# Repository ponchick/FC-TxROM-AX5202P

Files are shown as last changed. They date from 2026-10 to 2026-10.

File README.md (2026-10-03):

# FC-TxROM-AX5202P

Cartridge PCB with an MMC3 mapper built around the AX5202P IC.

In theory, such a cartridge should support all TxROM-family board types. In practice, only the most common variants have been tested — no issues were found.

Russian version: [`README.ru.md`](README.ru.md)

## PRG RAM and battery support

The board supports PRG RAM for save data. A CR2032 cell retains data when the console is powered off.

- **If a battery is installed** (saves are required) — leave the **NO BATTERY** jumpers **open** (do not bridge them).
- **If no battery is used** (PRG RAM is on the board but saves are not needed) — bridge **both** **NO BATTERY** jumpers. PRG RAM is then powered from the console’s main supply, and data is lost when power is removed.

In no-battery mode, the following parts may be omitted:

- Battery BT1
- Resistors R1, R2, R3, R4
- Capacitors C4, C8
- Diodes D1, D2
- Transistor Q1

## CHR ROM / CHR RAM selection

Some games need RAM instead of ROM for pattern tables. Selection is done with three jumpers on the board:

- **CHR ROM mode** — bridge the upper pair of pads.
- **CHR RAM mode** — bridge the lower pair of pads.

## Mirror Control (mapper 118 support)

The two **MIRROR CONTROL** jumpers route `CHR A17` and `CIRAM A10`. This is required for correct operation of different TxROM board subtypes.

- **Upper position** — for mapper 118 (**TKSROM** and **TLSROM** boards).
- **Lower position** — for standard TxROM (e.g. **TKROM**, **TLROM**) and most other MMC3 games.

If you do not use mapper 118, keep the jumpers in the lower position.

## ROM type selection (pinout)

Two jumpers switch pins 1 and 31 of the ROM IC, because those pins differ between memory types.

- **Upper position** (`EEPROM/FLASH`) — for electrically erasable ROM (EEPROM) and FLASH.
- **Lower position** (`UV EPROM`) — for UV-erasable EPROM.

Set the jumpers to match the ROM you install.

## License

This project is licensed under **CERN Open Hardware Licence Version 2 – Permissive** (`CERN-OHL-P-2.0`).  
See `LICENSE` for details.

SPDX-License-Identifier: `CERN-OHL-P-2.0`

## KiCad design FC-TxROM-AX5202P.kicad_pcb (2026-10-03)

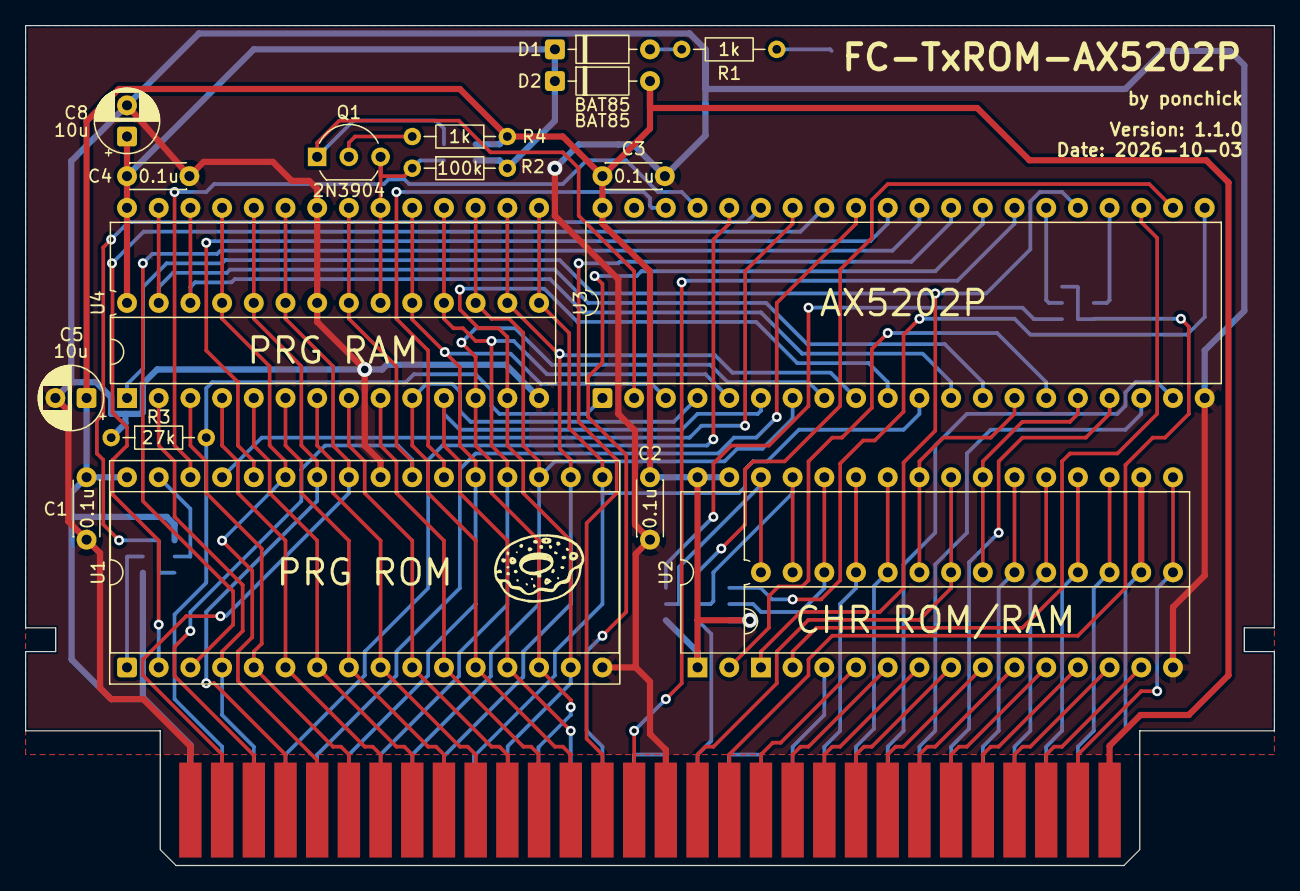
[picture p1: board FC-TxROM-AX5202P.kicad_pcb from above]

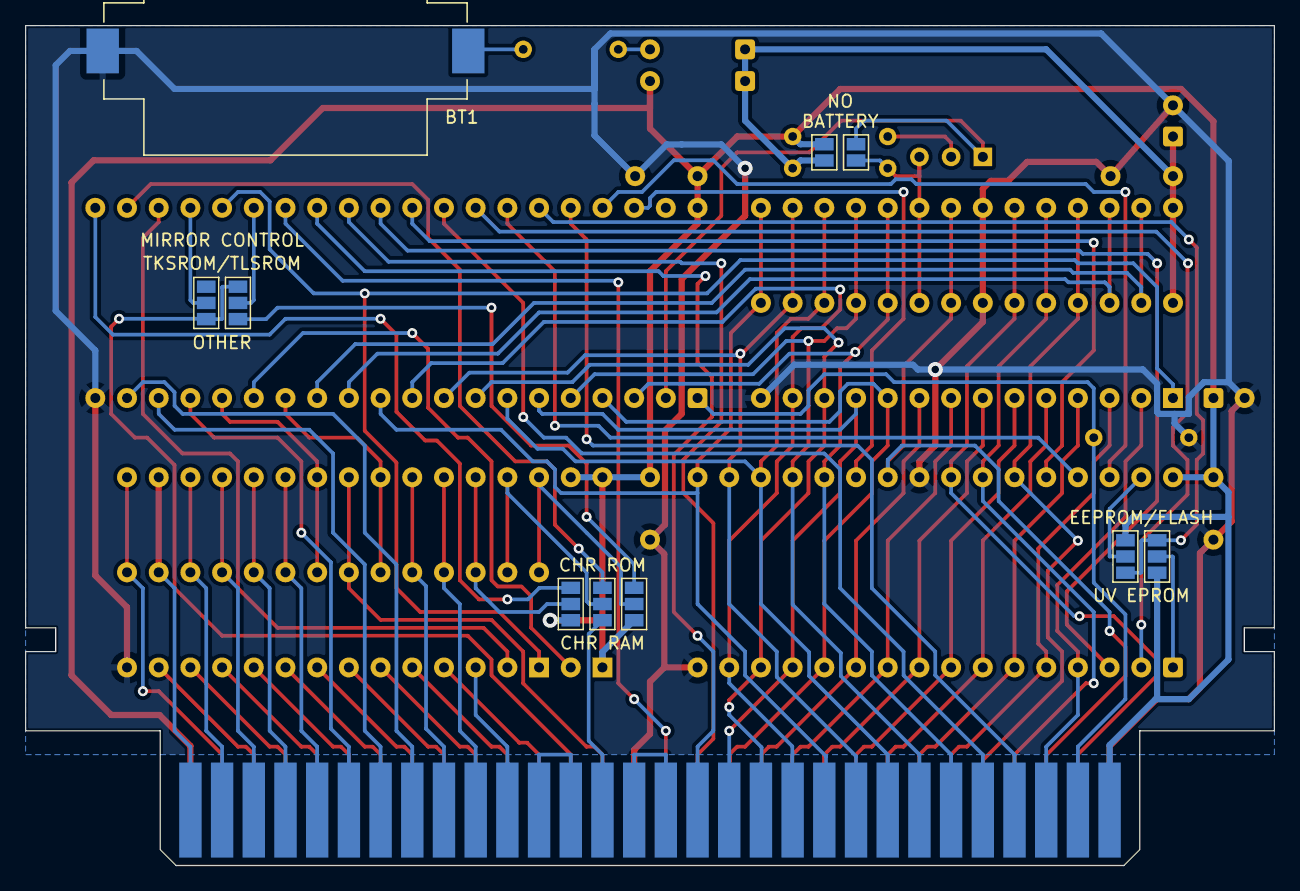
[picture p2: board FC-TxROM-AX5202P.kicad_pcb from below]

Board: 2 copper layers, 100.1 x 67.3 mm, 29 parts (10 on the bottom side), 86 nets.

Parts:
BT1: 2032; BatteryHolder_Keystone_1060_1x2032
C1, C2, C3, C4: 0.1u; C_Disc_D4.3mm_W1.9mm_P5.00mm
C5, C8: 10u; CP_Radial_D5.0mm_P2.50mm
D1, D2: BAT85; D_DO-35_SOD27_P7.62mm_Horizontal
J1: FAMICOM_EDGE; CONN_EDGE_2x60
JP1: +CE1 / A13; Jumper-3
JP2: ~{WE} / A14; Jumper-3
JP3, JP4: TKSROM/TLSROM/OTHER; Jumper-3
JP5: VDD / A17; Jumper-3
JP6, JP7: EPROM/FLASH; Jumper-3
JP8: UNSAFE_CE; SolderJumper-2_P1.3mm_Open_Pad1.0x1.5mm
JP9: SRAM_VCC; SolderJumper-2_P1.3mm_Open_Pad1.0x1.5mm
LOGO#: LOGO; ponchick
Q1: 2N3904; TO-92_Inline_Wide
R1, R4: 1k; R_Axial_DIN0204_L3.6mm_D1.6mm_P7.62mm_Horizontal
R2: 100k; R_Axial_DIN0204_L3.6mm_D1.6mm_P7.62mm_Horizontal
R3: 27k; R_Axial_DIN0204_L3.6mm_D1.6mm_P7.62mm_Horizontal
U1: PRG ROM; DIP-32_W15.24mm_Socket
U2: CHR ROM/RAM; DIP-32_Triple
U3: AX5202P; DIP-40_W15.24mm
U4: PRG RAM; DIP-28_Dual

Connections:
/CHR_A10: U2.23 (A10), U3.16 (CHR_A10)
/CHR_A11: U2.25 (A11), U3.14 (CHR_A11)
/CHR_A12: U2.4 (A12), U3.23 (CHR_A12)
/CHR_A13: JP1.1 (A), U3.21 (CHR_A13)
/CHR_A14: JP2.1 (A), U3.22 (CHR_A14)
/CHR_A15: U2.3 (A15), U3.25 (CHR_A15), U4.1 (NC)
/CHR_A16: U2.2 (A16), U3.15 (CHR_A16)
/CHR_A17: JP3.2 (C), U3.26 (CHR_A17)
/CHR_PIN26: JP1.2 (C), U2.28 (A13)
/CHR_PIN27: JP2.2 (C), U2.29 (A14)
/CHR_PIN28: JP5.2 (C), U2.30 (A17)
/CHR_PIN28_A17: JP3.3 (B), JP5.1 (A)
/CIRAM_A10: JP4.2 (C), U3.24 (CIRAM_A10)
/CPU_A0: J1.13 (CPU_A0), U1.12 (A0), U3.4 (CPU_A0), U4.10 (A0)
/CPU_A1: J1.12 (CPU_A1), U1.11 (A1), U4.9 (A1)
/CPU_A2: J1.11 (CPU_A2), U1.10 (A2), U4.8 (A2)
/CPU_A3: J1.10 (CPU_A3), U1.9 (A3), U4.7 (A3)
/CPU_A4: J1.9 (CPU_A4), U1.8 (A4), U4.6 (A4)
/CPU_A5: J1.8 (CPU_A5), U1.7 (A5), U4.5 (A5)
/CPU_A6: J1.7 (CPU_A6), U1.6 (A6), U4.4 (A6)
/CPU_A7: J1.6 (CPU_A7), U1.5 (A7), U4.3 (A7)
/CPU_A8: J1.5 (CPU_A8), U1.27 (A8), U4.25 (A8)
/CPU_A9: J1.4 (CPU_A9), U1.26 (A9), U4.24 (A9)
/CPU_A10: J1.3 (CPU_A10), U1.23 (A10), U4.21 (A10)
/CPU_A11: J1.2 (CPU_A11), U1.25 (A11), U4.23 (A11)
/CPU_A12: J1.33 (CPU_A12), U1.4 (A12), U4.2 (A12)
/CPU_A13: J1.34 (CPU_A13), U3.36 (CPU_A13)
/CPU_A14: J1.35 (CPU_A14), U3.32 (CPU_A14)
/CPU_D0: J1.43 (CPU_D0), U1.13 (D0), U3.6 (CPU_D0), U4.11 (Q0)
/CPU_D1: J1.42 (CPU_D1), U1.14 (D1), U3.8 (CPU_D1), U4.12 (Q1)
/CPU_D2: J1.41 (CPU_D2), U1.15 (D2), U3.10 (CPU_D2), U4.13 (Q2)
/CPU_D3: J1.40 (CPU_D3), U1.17 (D3), U3.11 (CPU_D3), U4.15 (Q3)
/CPU_D4: J1.39 (CPU_D4), U1.18 (D4), U3.9 (CPU_D4), U4.16 (Q4)
/CPU_D5: J1.38 (CPU_D5), U1.19 (D5), U3.7 (CPU_D5), U4.17 (Q5)
/CPU_D6: J1.37 (CPU_D6), U1.20 (D6), U3.5 (CPU_D6), U4.18 (Q6)
/CPU_D7: J1.36 (CPU_D7), U1.21 (D7), U3.3 (CPU_D7), U4.19 (Q7)
/CPU_RW: J1.14 (CPU_R/W), U3.29 (CPU_R/W)
/M2: J1.32 (M2), R3.2, U3.1 (M2)
/PPU_A0: J1.25 (PPU_A0), U2.12 (A0)
/PPU_A1: J1.24 (PPU_A1), U2.11 (A1)
/PPU_A2: J1.23 (PPU_A2), U2.10 (A2)
/PPU_A3: J1.22 (PPU_A3), U2.9 (A3)
/PPU_A4: J1.21 (PPU_A4), U2.8 (A4)
/PPU_A5: J1.20 (PPU_A5), U2.7 (A5)
/PPU_A6: J1.19 (PPU_A6), U2.6 (A6)
/PPU_A7: J1.50 (PPU_A7), U2.5 (A7)
/PPU_A8: J1.51 (PPU_A8), U2.27 (A8)
/PPU_A9: J1.52 (PPU_A9), U2.26 (A9)
/PPU_A10: J1.53 (PPU_A10), U3.19 (PPU_A10)
/PPU_A11: J1.54 (PPU_A11), U3.18 (PPU_A11)
/PPU_A12: J1.55 (PPU_A12), U3.17 (PPU_A12)
/PPU_A13: J1.56 (PPU_A13), U2.22 (CE)
/PPU_D0: J1.26 (PPU_D0), U2.13 (D0)
/PPU_D1: J1.27 (PPU_D1), U2.14 (D1)
/PPU_D2: J1.28 (PPU_D2), U2.15 (D2)
/PPU_D3: J1.29 (PPU_D3), U2.17 (D3)
/PPU_D4: J1.60 (PPU_D4), U2.18 (D4)
/PPU_D5: J1.59 (PPU_D5), U2.19 (D5)
/PPU_D6: J1.58 (PPU_D6), U2.20 (D6)
/PPU_D7: J1.57 (PPU_D7), U2.21 (D7)
/PRG_A13: U1.28 (A13), U3.31 (PRG_A13)
/PRG_A14: U1.29 (A14), U3.34 (PRG_A14)
/PRG_A15: U1.3 (A15), U3.30 (PRG_A15)
/PRG_A16: U1.2 (A16), U3.33 (PRG_A16)
/PRG_A17: U1.30 (A17), U3.37 (PRG_A17)
/PRG_A18: JP6.1 (A), JP7.3 (B), U3.35 (PRG_A18)
/PRG_PIN1: JP6.2 (C), U1.1 (A18)
/PRG_PIN31: JP7.2 (C), U1.31 (PGM)
/PRG_~CE: U1.22 (CE), U3.38 (PRG_~CE)
/VRAM_A10: J1.18 (CIRAM_A10), JP3.1 (A), JP4.3 (B)
/WRAM+CE: U3.12 (WRAM+CE), U4.26 (CS2)
/WRAM_SAFE_~CE: JP8.2 (B), Q1.3 (C), R2.1, U4.20 (~CS)
/WRAM_~CE: JP8.1 (A), Q1.1 (E), U3.2 (WRAM_~CE)
/WRAM_~WE: U3.13 (WRAM_~WE), U4.27 (~WE)
/~IRQ: J1.15 (~IRQ), U3.27 (~IRQ)
/~PPU_RD: J1.17 (~PPU_RD), U2.24 (OE)
/~PPU_WR: J1.47 (~PPU_WR), JP2.3 (B)
/~ROMSEL: J1.44 (~ROMSEL), U3.28 (~ROMSEL)
GND: BT1.2 (-), C1.2, C2.2, C3.2, C4.2, C5.2, C8.2, J1.1 (GND), J1.16 (GND), R3.1, U1.16 (GND), U1.24 (OE), U2.16 (GND), U3.20 (GND), U4.14 (GND), U4.22 (~OE)
unnamed: BT1.1 (+), R1.1
unnamed: D1.2 (A), R1.2
unnamed: J1.45 (AUDIO_IN), J1.46 (AUDIO_OUT)
unnamed: J1.48 (CIRAM_/CE), J1.49 (~PPU_A13)
unnamed: Q1.2 (B), R4.2
SRAM_VCC: C4.1, C8.1, D1.1 (K), D2.1 (K), JP9.2 (B), R2.2, U4.28 (VCC)
VCC: C1.1, C2.1, C3.1, C5.1, D2.2 (A), J1.30 (+5V), J1.31 (+5V), JP1.3 (B), JP5.3 (B), JP6.3 (B), JP7.1 (A), JP9.1 (A), R4.1, U1.32 (VCC), U2.1 (A18), U2.31 (PGM), U2.32 (VCC), U3.40 (VCC)

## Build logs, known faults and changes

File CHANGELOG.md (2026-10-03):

# Changelog

All notable changes to this project will be documented in this file.

The format is based on [Keep a Changelog](https://keepachangelog.com/en/1.1.0/),
and this project adheres to [Semantic Versioning](https://semver.org/spec/v2.0.0.html).

## [Unreleased]

## [1.1.0] - 2026-10-03

### Added

- Resistor R3 to pull the M2 line to ground.

## [1.0.1] - 2026-05-03

### Changed

- Update BOM name format in ibom.config.ini to use forward slashes for directory structure; no hardware changes.

## [1.0.0] - 2026-05-03

### Added

- Initial release of the FC-TxROM-AX5202P cartridge PCB.

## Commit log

2026-05-03 Update BOM name format in ibom.config.ini to use forward slashes for directory structure
2026-10-03 Release v1.1.0
    [FC-TxROM-AX5202P.kicad_pcb, FC-TxROM-AX5202P.kicad_sch]
